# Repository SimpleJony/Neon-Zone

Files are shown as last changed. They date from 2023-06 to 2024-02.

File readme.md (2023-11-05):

<div align="center">

Header Picture (https://imgse.com/i/piQY8Ld)
# Neon Zone
### A DIY pixel light based on ESP32

---
#### `Neon Zone`is a pixel light made based on ESP32. The display is driven by the light board of WS2812b, and the Arduino program is written and run. It is a pixel light integrating design and practicality

---
</div>

[中文](https://github.com/SimpleJony/Neon-Zone/blob/dev/readme_cn.md) | [English](https://github.com/SimpleJony/Neon-Zone/blob/dev/readme.md)

## 👐Get Started
### Material

* See "Material" folder for details.

### Program Compile
#### Tips:
* Program is written by Clion(~~vscode is good for it too~~) + platformio plugin, about how to configure PlatformIO,please refer to [this document](https://docs.platformio.org/en/latest/integration/ide/pioide.html)

* If it is difficult to configure the project in Clion, you can use vscode to configure the project and then write code in Clion

* The git submodule was used to write the program. After you clone the project, you need to execute the following Code in the code folder：
```
git submodule init
git submodule update
```

### 1. Clone the project with git command
```
git clone https://github.com/SimpleJony/Neon-Zone
```
### 2. Import project into Clion,wait for its initialization
Choose `Open` in Clion，select the `Code` folder，click `Open`
project-init (https://imgse.com/i/pPLKoIU)

## 📱Function
* **Control the light by XiaoAi**
* ESP32 SoftAP network configure mode
* Connect to the network, automatically get time, weather information
* Show time, weather
* Timer
* Snake
* Code rain animation

## Credits
* [SimpleJony](https://github.com/SimpleJony): Program the project
* [Kila](https://space.bilibili.com/278299486/?spm_id_from=333.999.0.0): Exterior Design & Model making
* [Blinker](https://github.com/blinker-iot): IoT Solution provider
* [QWeather](https://www.qweather.com/): Weather data provider
* [Arduino](https://github.com/arduino): Language used to write this project
* [Adafruit](https://github.com/adafruit): Libs used to control the light
* [JLC](https://www.jlc.com/): 3D print service provider

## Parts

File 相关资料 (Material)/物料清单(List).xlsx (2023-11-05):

购买物品 | 规格 | 参考链接 | 价格
开发板 | esp32-s2-pico x1 | 微雪ESP32-S2控制 0.96寸LCD显示屏扩展 WiFi开发板 支持Pico生态-淘宝网 (taobao.com) (https://item.taobao.com/item.htm?spm=a1z0d.6639537/tb.1997196601.21.7bbc7484vMuEHi&id=665270089564) | 58
WS2812模块 | 8x32 | pdd | 46
MPU-6050 陀螺仪 | x1 | MPU-6050三轴陀螺仪6DOF模块 GY-521 六轴姿态 三轴加速度传感器-淘宝网 (taobao.com) (https://item.taobao.com/item.htm?spm=a1z0d.6639537/tb.1997196601.22.5c2674848BQt7y&id=643832813465) | 9.9
pico拓展版 | x2 | YwRobot适用于树莓派Pico扩展板RaspberryPi开发板GPIO传感器模块-淘宝网 (taobao.com) (https://item.taobao.com/item.htm?spm=a1z09.2.0.0.e6832e8ddohBpa&id=639884382910&_u=n20c1n5iqu7802) | 70
摇杆 | x2 | pdd | 6.9
蜂鸣器 | 3v x5 | pdd | 6.75
dc电源 | 12v | pdd | 16
金属按钮 | x2 | pdd | 3.9
 |  |  | 217.45

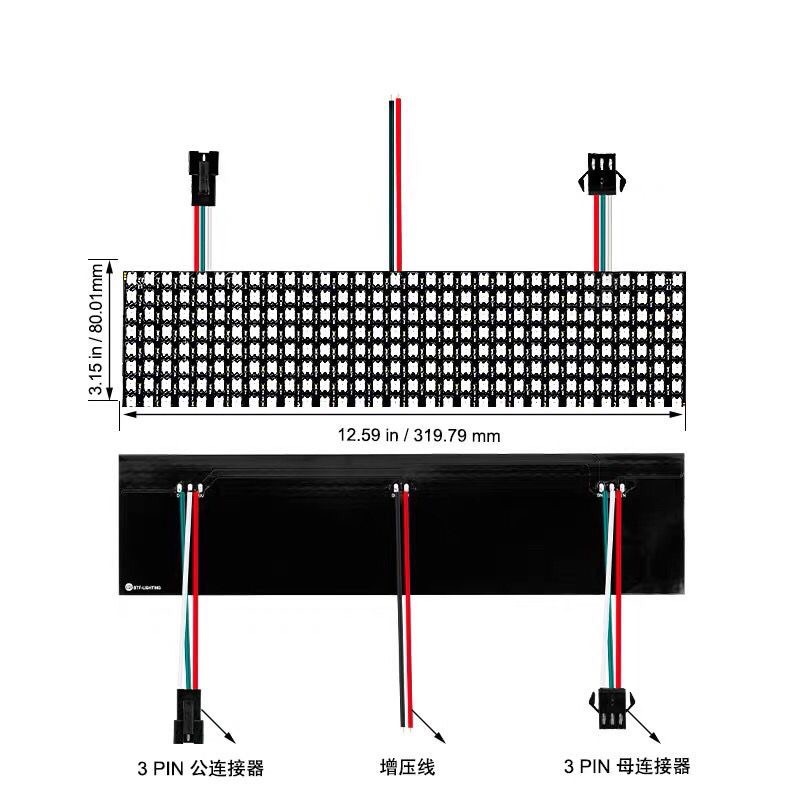
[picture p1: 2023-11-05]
相关资料 (Material)/尺寸(Size).jpg

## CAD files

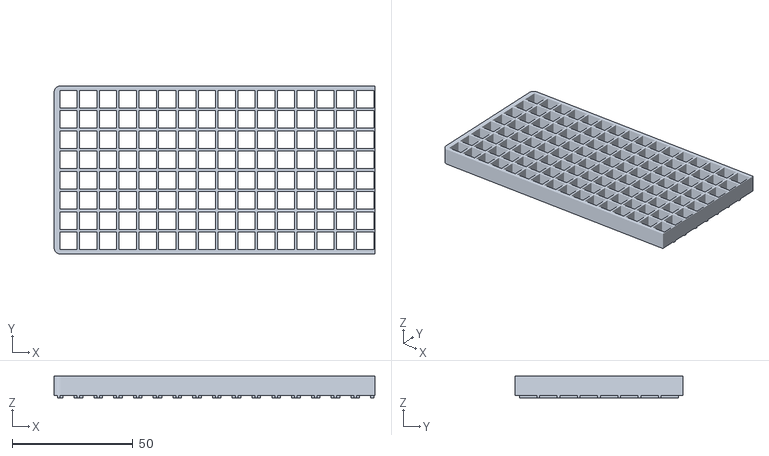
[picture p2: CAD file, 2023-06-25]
Model/格栅.STL
132.8 x 69.6 x 9.00

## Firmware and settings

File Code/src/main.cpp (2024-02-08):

#define BLINKER_PRINT Serial
#define BLINKER_WIFI
#define BLINKER_ESP_TASK
#define BLINKER_MIOT_LIGHT
#include <Arduino.h>
#include <Blinker.h>
#include <WiFi.h>
#include "Draw/ShowThings.h"
#include "Draw/DrawAnimation.h"
#include "Draw/ShowMenu.h"
#include "BlinkerControl/XiaoAiControl.h"
#include "Tools/config.h"
#include "SoftAP/SoftAP.h"

// 函数声明
void onBoot();

void setup(){
    Serial.begin(115200);
    onBoot();
}

void loop(){
    checkDNS();
    if (WiFi.status() == WL_CONNECTED){
        if (is_APmode){
            ESP.restart();
        }
        ShowMenu();
    }
    delay(200);
}

/*
    onBoot函数实现，在开机时执行相应命令
    Date: 2023.7.31
    Author: Jony
*/
void onBoot(){
    #if defined(BLINKER_PRINT)
    BLINKER_DEBUG.stream(BLINKER_PRINT);
    #endif
    EEPROM.begin(3100);
    matrix.begin();
    matrix.setBrightness(Brightness);
    matrix.setRotation(2);
    matrix.show();
    rainbowLight();
    delay(2000);
    matrix.clear();
    delay(1000);
    drawWifi();
    drawArrow();
    EEPROM.get(3000, countdown_year);
    EEPROM.get(3000 + sizeof(int), countdown_month);
    EEPROM.get(3000 + 2 * sizeof(int), countdown_day);
    connectWifi(connectTimeOut);
    if (WiFi.status() == WL_CONNECTED){
        matrix.clear();
        drawWifi();
        drawSuccess();
        delay(1000);
        Blinker.begin(auth,WiFi.SSID().c_str(),WiFi.psk().c_str());
        BLINKER_TAST_INIT();
        Blinker_callback();
        configTime(gmtOffset_sec, daylightOffset_sec, ntpServer);
        weatherNow.config(UserKey,location_code);
        while (!weatherNow.get()) {
            if (weatherRetryTime == 5){
                Serial.println("Weather data receive failed.");
                break;
            }
            weatherRetryTime++;
            delay(1000);
        }
        matrix.clear();
    }
}

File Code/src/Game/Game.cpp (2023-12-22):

//
// Created by jonyl on 2023/9/10.
//
#include "Game.h"

void resetGame(Snake* snake, Food &food, int &snake_length, int &snake_speed, int &snake_x, int &snake_y, int &snake_r, int &snake_g, int &snake_b, String &direction) {
    joystick_x = 0;
    joystick_y = 0;

    snake_length = 3;
    snake_speed = 100;
    snake_x = 0;
    snake_y = 0;
    snake_r = 255;
    snake_g = 0;
    snake_b = 0;
    direction = "right";

    matrix.begin();
    matrix.setTextWrap(false);
    matrix.setBrightness(50);
    matrix.fillScreen(matrix.Color(0, 0, 0));
    matrix.show();

    randomSeed(analogRead(0));
    food.x = random(SCREEN_WIDTH);
    food.y = random(SCREEN_HEIGHT);
    food.r = 255;
    food.g = 255;
    food.b = 255;

    for (int i = 0; i < snake_length; i++) {
        snake[i].x = snake_x - i;
        snake[i].y = snake_y;
        snake[i].r = snake_r;
        snake[i].g = snake_g;
        snake[i].b = snake_b;
    }
}


void snakeGame() {
    joystick_x = 0;
    joystick_y = 0;

    Snake* snake = new Snake[SCREEN_WIDTH * SCREEN_HEIGHT];
    Food food;

    int snake_length = 3;
    int snake_speed = 100;
    int snake_x = 0;
    int snake_y = 0;
    int snake_r = 255;
    int snake_g = 0;
    int snake_b = 0;
    String direction = "right";

    matrix.begin();
    matrix.setTextWrap(false);
    matrix.setBrightness(50);
    matrix.fillScreen(matrix.Color(0, 0, 0));
    matrix.show();

    randomSeed(analogRead(0));
    food.x = random(SCREEN_WIDTH);
    food.y = random(SCREEN_HEIGHT);
    food.r = 255;
    food.g = 255;
    food.b = 255;

    for (int i = 0; i < snake_length; i++) {
        snake[i].x = snake_x - i;
        snake[i].y = snake_y;
        snake[i].r = snake_r;
        snake[i].g = snake_g;
        snake[i].b = snake_b;
    }
    while (now_state == "snakegame") {
        buttonState_c = digitalRead(14);
        buttonState_e = digitalRead(34);
        if (BlinkerButtonState_exit == "tap" || buttonState_e == 0){
            BlinkerButtonState_exit = "null";
            matrix.clear();
            delete[] snake;
            now_state = "menu";
            ShowMenu();
        }

        joystick_x = analogRead(adc0);
        joystick_y = analogRead(adc1);

        if ((joystick_x != 0 && joystick_y == 0 && direction != "down") || ((BlinkerY >= 0 && BlinkerY <=5) && direction != "down")) direction = "up";
        else if ((joystick_x != 0 && joystick_y == 8191 && direction != "up") || ((BlinkerY >= 250 && BlinkerY <=255) && direction != "up")) direction = "down";
        else if ((joystick_x == 0 && joystick_y != 0 && direction != "right") || ((BlinkerX >= 250 && BlinkerX <=255) && direction != "right")) direction = "left";
        else if ((joystick_x == 8191 && joystick_y != 0 && direction != "left") || ((BlinkerX >= 0 && BlinkerX <=5) && direction != "left")) direction = "right";

        if (direction == "right") snake_x++;
        else if (direction == "left") snake_x--;
        else if (direction == "up") snake_y--;
        else if (direction == "down") snake_y++;

        if (snake_x < 0 || snake_x >= SCREEN_WIDTH || snake_y < 0 || snake_y >= SCREEN_HEIGHT) {
            matrix.clear();
            matrix.fillScreen(matrix.Color(255,0,0));
            matrix.show();
            delay(1000);
            matrix.clear();
            drawScore();
            delay(1000);
            if (snake_length-3 > 9){
                drawNumber(23,1,(snake_length-3)/10,255,163,177,Brightness);
                drawNumber(28,1,(snake_length-3)%10,255,163,177,Brightness);
            }
            else {
                drawNumber(23,1,snake_length-3,255,163,177,Brightness);
            }
            delay(3000);
            resetGame(snake, food, snake_length, snake_speed, snake_x, snake_y, snake_r, snake_g, snake_b, direction);
        }

        for (int i = 1; i < snake_length; i++) {
            if (snake[i].x == snake_x && snake[i].y == snake_y) {
                matrix.clear();
                matrix.fillScreen(matrix.Color(255,0,0));
                matrix.show();
                delay(1000);
                matrix.clear();
                drawScore();
                delay(1000);
                if (snake_length-3 > 9){
                    drawNumber(23,1,(snake_length-3)/10,255,163,177,Brightness);
                    drawNumber(28,1,(snake_length-3)%10,255,163,177,Brightness);
                }
                else {
                    drawNumber(23,1,snake_length-3,255,163,177,Brightness);
                }
                delay(3000);
                resetGame(snake, food, snake_length, snake_speed, snake_x, snake_y, snake_r, snake_g, snake_b, direction);
            }
        }

        if (snake_x == food.x && snake_y == food.y) {
            snake_length++;
            food.x = random(SCREEN_WIDTH);
            food.y = random(SCREEN_HEIGHT);
        }

        for (int i = snake_length - 1; i > 0; i--) {
            snake[i].x = snake[i - 1].x;
            snake[i].y = snake[i - 1].y;
        }
        snake[0].x = snake_x;
        snake[0].y = snake_y;
        matrix.fillScreen(matrix.Color(0, 0, 0));
        for (int i = 0; i < snake_length; i++) {
            matrix.drawPixel(snake[i].x, snake[i].y, matrix.Color(snake[i].r, snake[i].g, snake[i].b));
        }

        matrix.drawPixel(food.x, food.y, matrix.Color(food.r, food.g, food.b));
        matrix.show();
        delay(snake_speed);
    }
}

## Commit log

2023-06-25 Project: Initial commit
    [格栅.STL, 物料清单.xlsx]
2023-07-28 [Feature] Draw "Timer"
2023-07-28 [Fix] Show matrix when draw is done
    [main.cpp]
2023-07-31 [Fix] Change serial baud to 9600
    [main.cpp]
2023-07-31 Update files
    [物料清单.xlsx]
2023-07-31 [Improve] Use a function to execute codes when device is booting
2023-07-31 [Fix] Delete unfinished function
    [main.cpp]
2023-07-31 [Fix] Drop getJoystickData function * After this, some functions can get joystick_x and joystick_y
    [main.cpp]
2023-08-02 [Fix] Add matrix.show() for drawGame()
    [main.cpp]
2023-08-02 [Fix & Improve] Simplify code, fix wrong positions of light
    [main.cpp]
2023-08-04 [Improve] Decrease rainbowLight delay time * Too slow for a startup animation
    [main.cpp]
2023-08-04 [Fix & Improve] Finish drawNumber() and optimize showTime() * The original function was written by AI, which is not completed,finish now.
    [main.cpp]
2023-08-04 [Fix] Fix time refresh time
    [main.cpp]
2023-08-04 [Fix] Clear matrix after onBoot()
    [main.cpp]
2023-08-04 [Fix] Add delay after drawSuccess()
    [main.cpp]
2023-08-18 [Improve] Remove useless messages when can't get weather data * If device can't connect to wifi,it will reboot,so it's useless after connectWifi function
    [main.cpp]
2023-08-18 [Fix] Get weather after config * Forget to get weather data
    [main.cpp]
2023-08-19 [Project] Use ArduinoUZlib as a submodule
2023-09-10 [Feature] Add exit function feature * We need a function to exit,so we can return to main menu. * (So tired after writing this,spend all day on it.) * Only have virtual button now,will add real butto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
2023-09-16 [Improve] Redesign "Time" text * A littie improve,previous comes from "Timer",some words' position are not right,so redesign it
2023-09-17 [Feature] Add timer feature * Add a timer, getting more innovation
2023-09-17 [Fix] Add entrance for timer * If there's not an entrance,how to get into it?
    [ShowMenu.cpp]
2023-09-29 [Improve] Fix while condition * Change while condition according to now_state
    [Game.cpp, ShowMenu.cpp, ShowThings.cpp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]
2023-10-01 [Feature] Allow user to reset game * Need to reset game after u died! * About how to draw snake,did some improvements
    [Game.cpp, ShowMenu.cpp]
2023-10-02 [Improve] Add "Info" page to show time,timer,and weather * If we want to draw "weather" on the screen,it can't fit well,so we add a info page,show these info as an icon
2023-10-02 [Fix] Delete "connectWifi" function * We have already configured wifi in Blinker,so when we execute "BLINKER_TAST_INIT()" function,it will connect to wifi.If we use one more function to connect to wi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
    [main.cpp]
2023-10-02 [Fix] Update weather code if can't get weather data * If we can't get weather data,the weather code is 999,then we should draw "unknown"
    [ShowThings.cpp]
2023-10-02 Revert "[Fix] Update weather code if can't get weather data"
    This reverts commit 4b75b97799594dc5a267edb597071fb5e0bd7a85.
    [ShowThings.cpp]
2023-10-03 [Fix] Read joystick data in Timer * Forget to read joystick data
    [Timer.cpp]
2023-10-03 [Improve] Change the color when timer is set * Better way to remind user
2023-10-03 [Fix] Fix timer's logical problem * There's a problem on setting timer.Now fixed
    [Timer.cpp]
2023-10-03 [Fix] Correct joystick condition * Wrong joystick condition set,cause unexpected error
    [Timer.cpp]
2023-10-03 [Fix] Change condition in time,timer and weather * Since we introduced "info" page,we need to change condition to let XiaoAi control them.So we need to get into ShowInfo(),then these mode.
2023-10-03 [Fix] Change while condition in timer * We need to set all while condition to "now_state == "timer" "
    [Timer.cpp]
2023-10-15 [Improve] Change the color when the timer is end * Give user better response
2023-11-03 [Fix] Using the same version ArduinoJson * We need to use the same version of ArduinoJson,otherwise it will show some strange errors (QwQ use 2 months to fix this problem!!!)
2023-11-04 [Improve] Remove useless undef code
    * SInce we found that what caused ArduinoJson compiles error,so we deleted the wrong code we wrote before
    [main.cpp]
2023-11-05 [Update] Update more information * Upload previous materials
    [物料清单(List).xlsx, 物料清单.xlsx]
2023-11-07 [Improve] Restore wifi data through a button * Allow to restore wifi data with pressing a button
2023-11-09 [Fix] Use while to get weather data when return false * Previous way to get data is wrong,so rewrite now
    [main.cpp]
2023-11-12 [Feature] Adapt for real button * Now we have real button to control!
2023-11-12 [Fix] Submit missing code * Forget to add files to git :(
    [main.cpp]
2023-11-12 [Improve] Adapt real button for Code Rain * Forget to adapt this
2023-11-14 [Fix] Update exit button GPIO * DK Why previous GPIO won't work,so change
    [Game.cpp, ShowMenu.cpp, ShowThings.cpp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]
2023-11-14 [Fix] Set rotation to WS2812 * We made a mistake on assembling the model,so set rotation on program.
    [main.cpp]
2023-11-14 [Fix] Add delay to timer when button pressed * Need to add a delay in Timer,otherwise it will broken
    [Timer.cpp]
2023-11-16 [TEST][Fix] Fix memory leak in snake game * May fix memory leak in snake game, test later
    [Game.cpp]
2023-11-16 [Fix] Delete useless button detection code * Change button's GPIO,previous won't work now
    [ShowThings.cpp]
2023-12-22 Revert "[TEST][Fix] Fix memory leak in snake game"
    This reverts commit 56f581f99b532dd1a466accfd5c8fa1b9fb80aa9.
    [Game.cpp]
2023-12-22 [Fix] Fix memory leak in snake game * Memory leak in snake will let board crash after get into the game twice,now use pointer instead of array to avoid this problem
    [Game.cpp]
2024-02-08 [Improve] Clear the screen when timer is done * Have better notification
2024-02-08 [Improve] Push current mode data to Blinker
2024-02-09 [Improve] Adapt wifi restore function to button * We used to adapt for blinker button,now for real button
2024-02-19 [Fix] Don't set brightness in snake game * We need to unify the brightness of entire system
    [Snake.cpp]
2024-02-19 [Fix] Assign light_state and reset buttonState * Forget to assign light_state * Need to reset buttonState,otherwise it will loop in 0 and 1
    [ShowThings.cpp]
2024-02-19 [Fix] Delete wifi restore adaptation for real button * Don't want to deal with long press adaptation,if we press the button in menu,it will restore wifi data and reboot.So let just use this function 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
    [ShowMenu.cpp]
